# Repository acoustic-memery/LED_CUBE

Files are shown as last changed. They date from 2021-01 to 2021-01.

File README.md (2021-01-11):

# 8X8X8 LED_CUBE


 Code and other bits for my 8x8x8 LED cube

#  File Directory
- CAD_FILES: Includes all CAD used to design 3D printed casing for the cube
- Gerbers_Main: Gerber files generated from my designs in KiCAD and used to manufacture Arduino Breakout PCB
- Gerbers_Secondary: Gerber files generated from my designs in KiCAD and used to manufacture register array PCB
- LED_CUBE_CURRENT: Current software used to run LED cube, all code written in C/C++ on the platformio Arduino framework
- 8x8x8_cube_old.ino: Old Arduino IDE based project
- LED_CUBE_DEMO: HIRE ME :) Demo

#  Project Details

After seeing seeing similar cubes on reddit, I became inspired and wanted to build my own. There were several guides on the internet but they seemed to be using older hardware and could be improved upon significantly. I sought out to do this and designed control PCBs, software, physical casing as well as hand soldered array.

#  How it works:

This cube uses the concept of LED multiplexing, basically only having one of the 8 vertical layers on at once but running through each of these layers so fast that the human eye is tricked and thinks its seeing a still image. More techinically it is controlled by an Arduino Nano to control a single layer of 64 lights. Because the Nano doesn't have 64 GPIO pins, it utilizes 8 of them to write to an 8-bit shift register each. The shift register then "stores" and outputs the associated off or on value for an entire row of 8 lights. Now we have what is essentially a serial to parallel buffer which enables to nano to output a layer at a time. On the Arduino breakout board there is also an external power supply that is designed to work with 7-12 volts input and up to 1.5A input.

See schematics below:

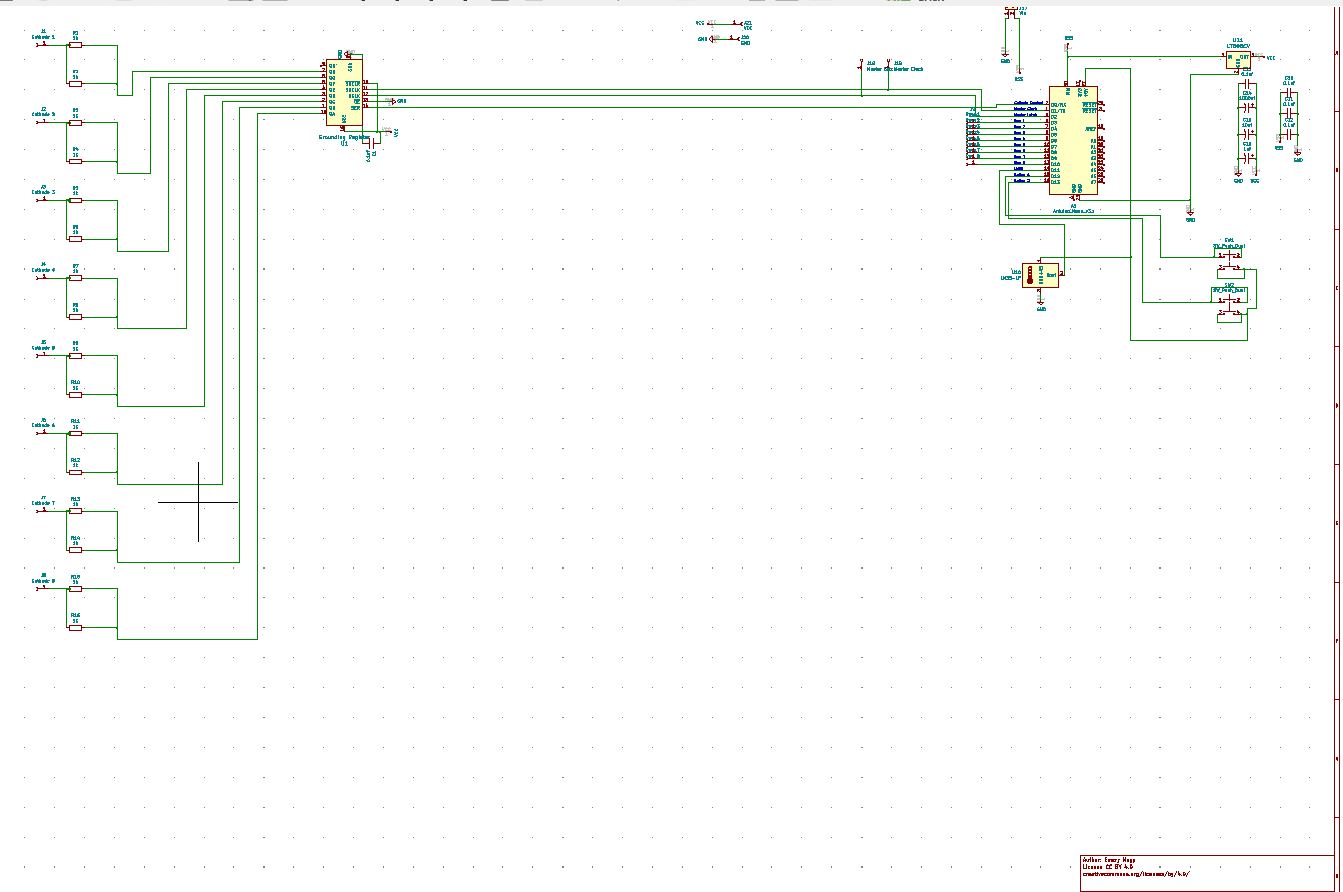
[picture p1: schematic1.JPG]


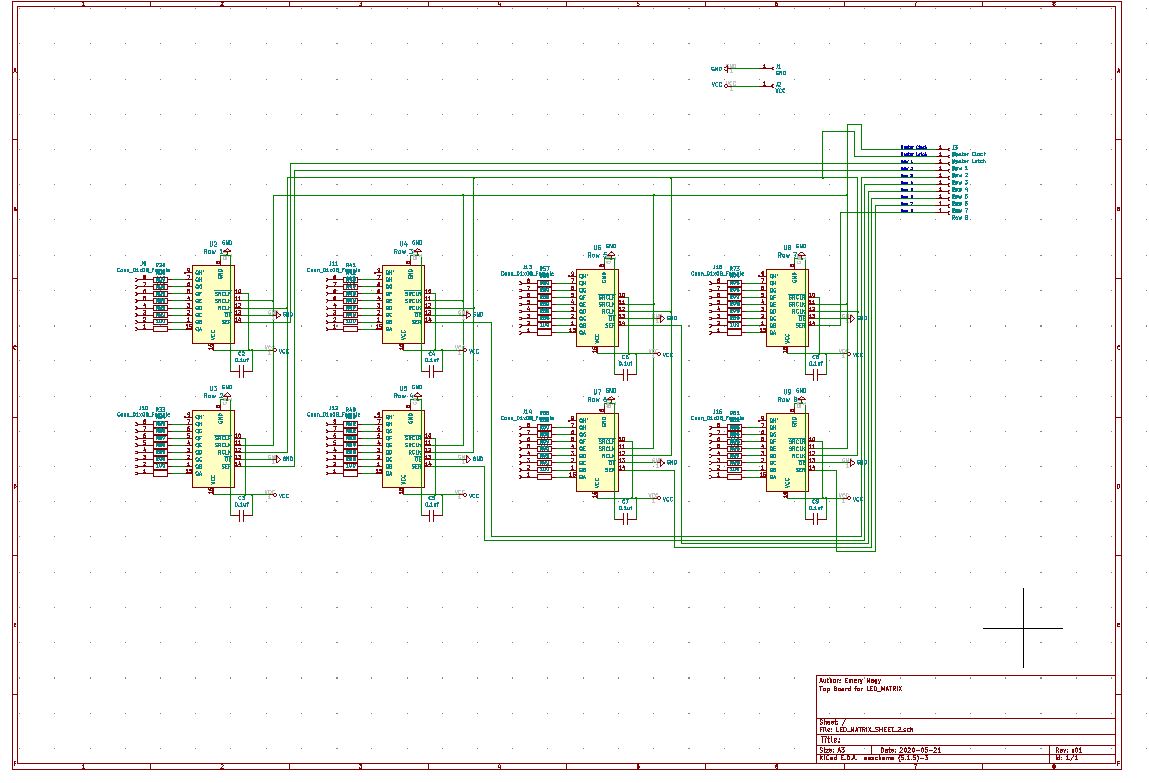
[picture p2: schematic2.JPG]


The software was origionally written just using the basic Arduino IDE, but soon moved over to Platformio for more flexability. The core of the software design involves writing bits to a 2D byte array where each byte can be thought of to corispond to a row in the *X AXIS* of the cube and the other two dimensions of the array can be thought of to contain the *Y AND Z AXIS* accoridingly. In order to output to the shift registers efficiently custom drivers were needed which utiized the idea of "bit banging" or using the digital output of the GPIO to generate the digital signal as well as clock signal.

The housing was designed in SOLIDWORKS and 3D printed in silver/grey PLA. It was designed to be assembled with Zipties because I am classy...

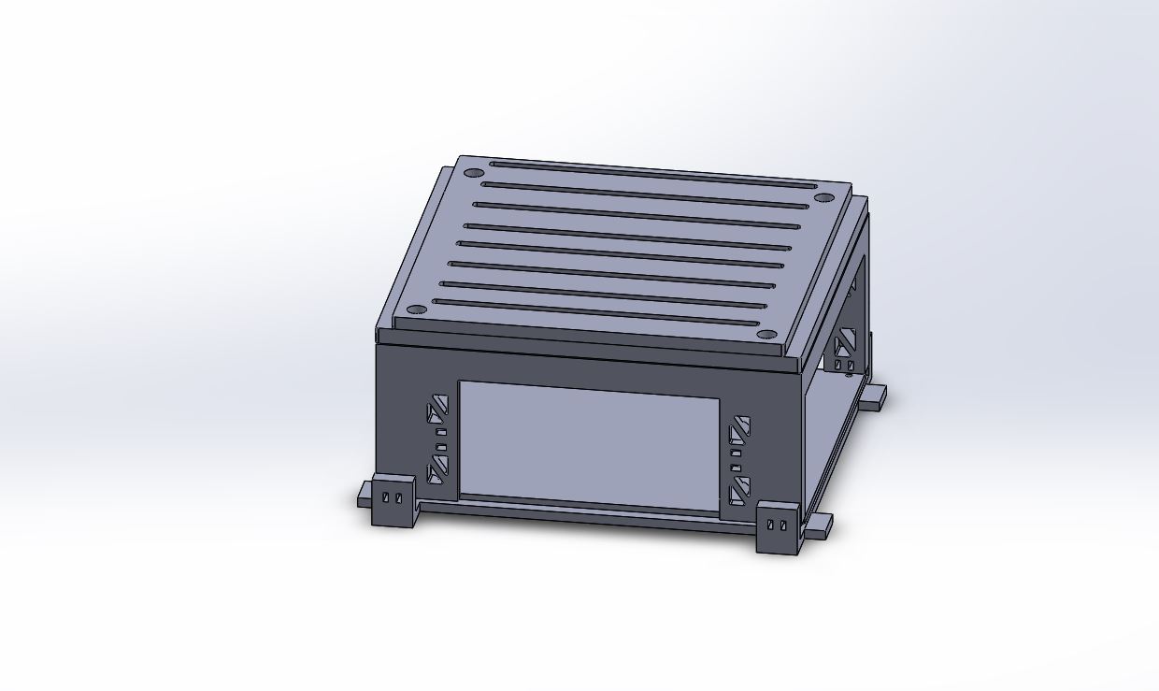
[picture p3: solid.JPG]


Overall this was a super fun project and taught me a lot of awesome skills!

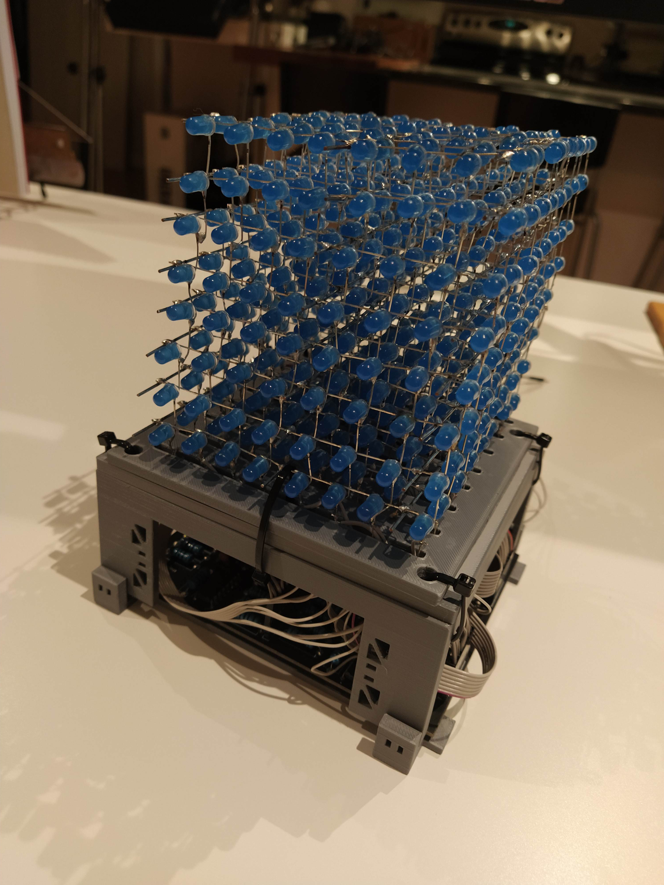
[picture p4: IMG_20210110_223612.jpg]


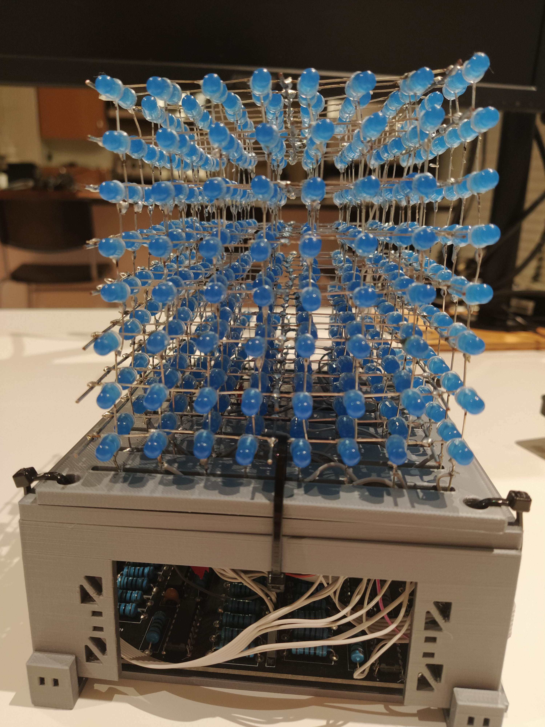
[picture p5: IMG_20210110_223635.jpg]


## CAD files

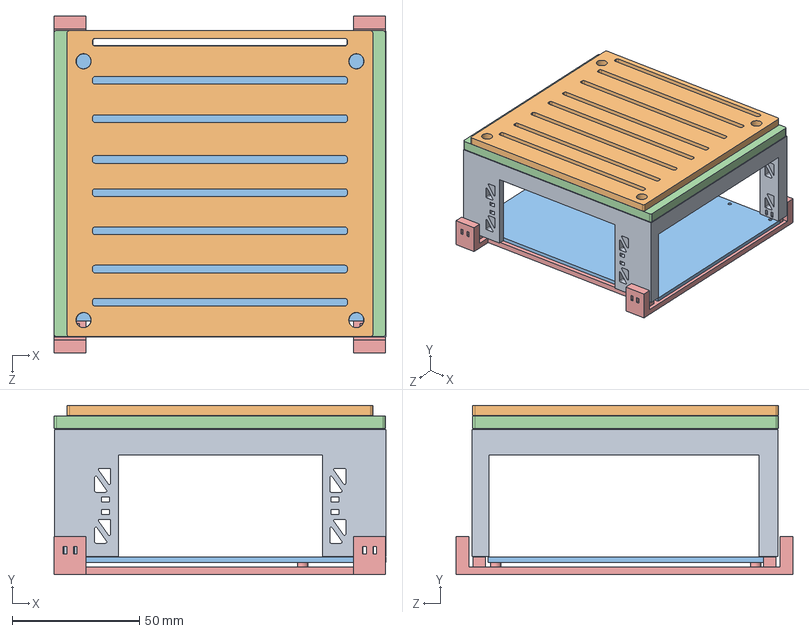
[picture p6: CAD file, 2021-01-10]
CAD_FILES/Assembly master.SLDASM
130.2 x 66.4 x 132.0 mm
Mid Plate 1
Top plate 1
register_PCB
Spacer_Top
register_PCB_Holder

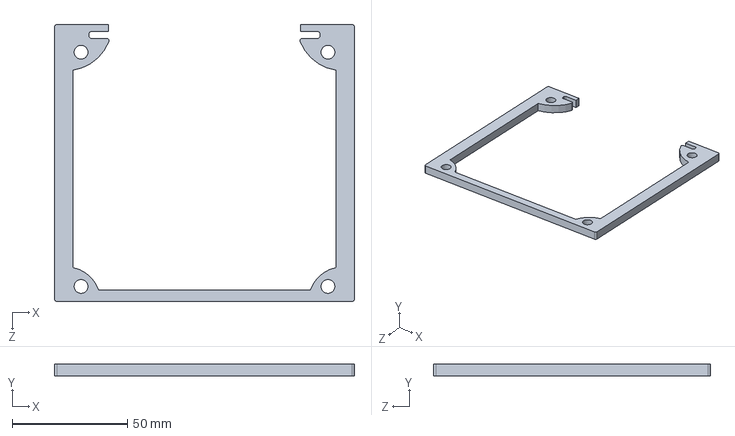
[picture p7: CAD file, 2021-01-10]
CAD_FILES/Spacer_Top.SLDPRT
130.0 x 5.00 x 120.0 mm

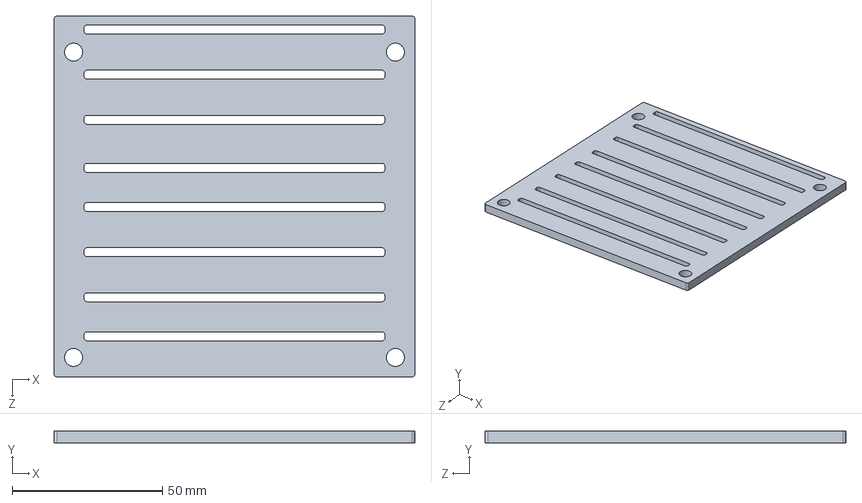
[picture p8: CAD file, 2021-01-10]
CAD_FILES/Top plate 1.SLDPRT
120.0 x 4.00 x 120.0 mm

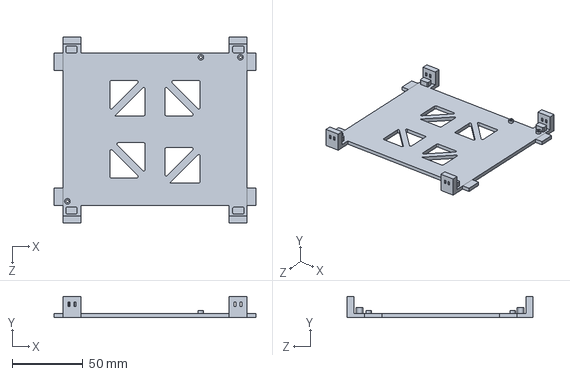
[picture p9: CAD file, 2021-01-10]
CAD_FILES/register_PCB_Holder.SLDPRT
143.0 x 15.0 x 132.0 mm

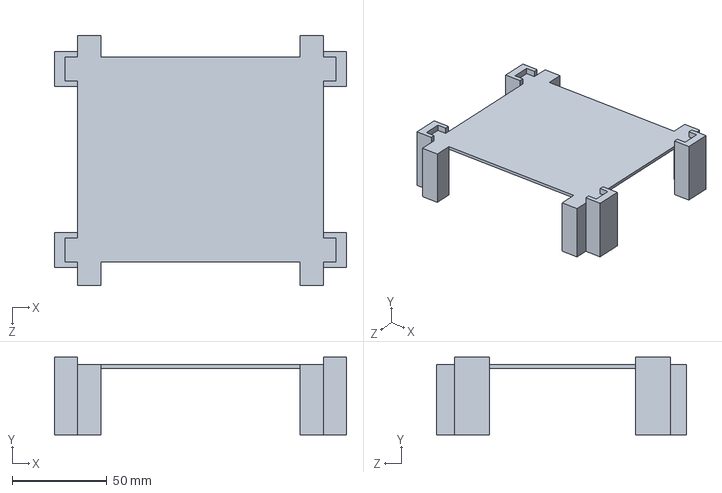
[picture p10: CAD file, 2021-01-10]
CAD_FILES/Controller_PCB_Holder.SLDPRT
154.0 x 41.0 x 132.0 mm

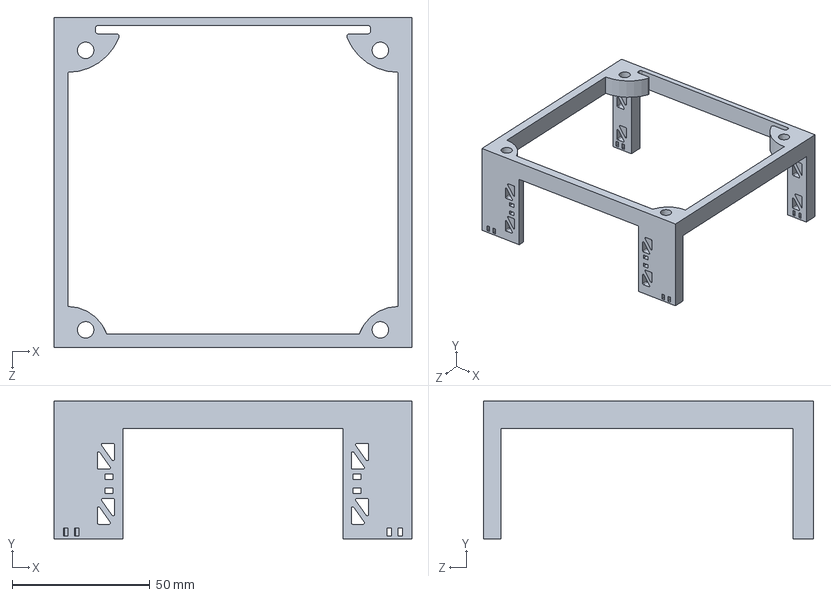
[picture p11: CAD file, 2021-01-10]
CAD_FILES/Mid Plate 1.SLDPRT
130.0 x 50.0 x 120.0 mm

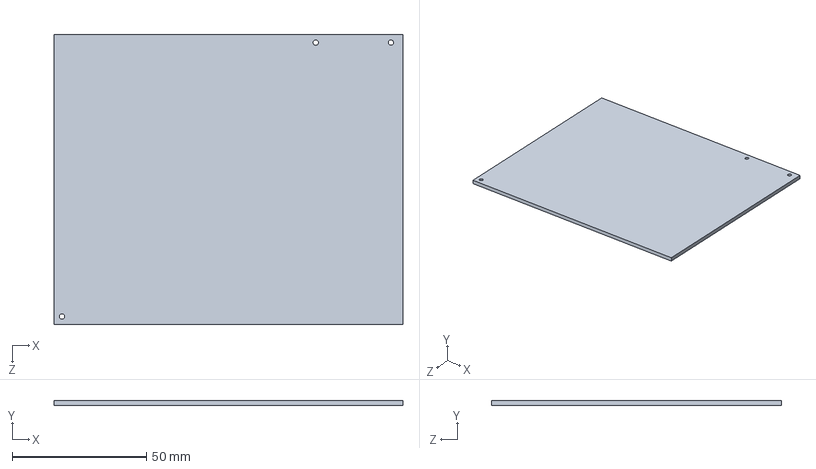
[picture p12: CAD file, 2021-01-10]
CAD_FILES/register_PCB.SLDPRT
130.0 x 2.00 x 108.0 mm

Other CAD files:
CAD_FILES/Mid Plate 1.STL
CAD_FILES/Spacer_Top.STL
CAD_FILES/Top plate 1.3mf
CAD_FILES/Top plate 1.STL
CAD_FILES/register_PCB_Holder.STL

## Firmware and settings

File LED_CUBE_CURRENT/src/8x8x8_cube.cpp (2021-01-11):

//Control Program for an 8x8x8 LED cube
//Author: Emery Nagy
//Date: Aug 21, 2020
//

// Globals
#include <Arduino.h>
#include <SoftwareSerial.h>
#define x_z 0
#define y_z 1
#define x_y 2

const int groundPin = 0;  //data pin for ground layers
const int latchPin = 2; 
const int clockPin = 1;
const int row1 = 3;
const int row2 = 4;
const int row3 = 5;
const int row4 = 6;
const int row5 = 7;
const int row6 = 8;
const int row7 = 9;
const int row8 = 10;
//SoftwareSerial mySerial(11, 12); //soft serial init
 
void setup() {
  // initialize I/O pins
  pinMode(groundPin, OUTPUT);
  pinMode(latchPin, OUTPUT);
  pinMode(clockPin, OUTPUT);
  pinMode(row1, OUTPUT);
  pinMode(row2, OUTPUT);
  pinMode(row3, OUTPUT);
  pinMode(row4, OUTPUT);
  pinMode(row5, OUTPUT);
  pinMode(row6, OUTPUT);
  pinMode(row7, OUTPUT);
  pinMode(row8, OUTPUT);
 
 // mySerial.begin(9600);
}

byte cube[8][8]; //create an empty 2d byte array which can be used to specify y and z axis in which bits get modified


/*////////////////////////////////////////////////////////////////////////////////////////////////////
Custom shiftout function

-> (Output): Draws a complete X-Y layer i.e. 64 flat nodes

-> (PARAM): Takes an 8 bit value for each row where each bit corisponds to a "node on the x axis" and each row corisponds to the equivelent y axis

-> (PARAM): Takes the ground value
    -> "Ground value" needs to be low for the given layer to be on

*///////////////////////////////////////////////////////////////////////////////////////////////////

void shift(uint8_t val,uint8_t val_2, uint8_t val_3, uint8_t val_4, uint8_t val_5, uint8_t val_6, uint8_t val_7, uint8_t val_8, uint8_t val_ground, int frame_delay) //shift out all 8 rows as well as ground layer row
{
    digitalWrite(latchPin,LOW); //lower latch of each register
     uint8_t i;
     for (i = 0; i < 8; i++)  {
                 digitalWrite(row1, !!(val & (1 << i))); //write the bit of each row
                 digitalWrite(row2, !!(val_2 & (1 << i)));
                 digitalWrite(row3, !!(val_3 & (1 << i)));
                 digitalWrite(row4, !!(val_4 & (1 << i)));
                 digitalWrite(row5, !!(val_5 & (1 << i)));
                 digitalWrite(row6, !!(val_6 & (1 << i)));
                 digitalWrite(row7, !!(val_7 & (1 << i)));
                 digitalWrite(row8, !!(val_8 & (1 << i)));
                 digitalWrite(groundPin, !!(val_ground & (1 << i))); //set the ground pin
           digitalWrite(clockPin, HIGH); //write to the clock
           digitalWrite(clockPin, LOW);       
}
   digitalWrite(latchPin,HIGH); //set the latch high
   //delayMicroseconds(frame_delay);
}


/*//////////////////////////////////////////////////////////////////////////////////////////////////
Frame drawing function

-> (Output): Print a whole 3d frame by using the technique of LED multiplexing
  -> LED multiplexing involves setting each layer and running through them very quickly, giving an illusion of a 3D effect


-> (PARAM): iterations: Number of times the frame should be drawn

-> (PARAM): layer: frame layer preset to run (by default to be ground for one layer at a time)

*////////////////////////////////////////////////////////////////////////////////////////////////////
void frame(int f_delay[], int iterations, uint8_t layer[]){ //shift out all 64 bytes in frame buffer
  int n;
  for(n = 0; n < iterations; n++){ //run the total number of iterations
  int i;
  for (i = 0; i < 8; i++){ //run through each layer in the frame buffer
   shift(cube[0][i], cube[1][i], cube[2][i], cube[3][i], cube[4][i], cube[5][i], cube[6][i], cube[7][i], layer[i], f_delay[i]); //shiftout layers
  }}  
  }

uint8_t layer[8] = {B01111111, B10111111, B11011111, B11101111, B11110111, B11111011, B11111101, B11111110}; //ground layer presets

int delay_amount[8] = {5, 5, 5, 5, 5, 5, 5, 5}; //delay presets

int inRange(int num){ //chack if inputs fit within the 8x8x8 cube
  if (0 <=num <=7){
    return 1;
    }
    else{
      return 0;
      }}

/*//////////////////////////////////////////////////////////////////////////////////////////////////////////////////////////

setNode and clearNode

-> (PARAM): x, y, z: The address (physical location) of bit to be set or cleared

-> (OUTPUT): set or clear specific node at value x, y, z
*//////////////////////////////////////////////////////////////////////////////////////////////////////////////////////////
void setNode(int x, int y, int z){ //set a specified node at x, y, z
  if ((inRange(x)) && (inRange(y)) && (inRange(z))){ //make sure that the node to be set is in range of the cube and buffer
  cube[y][z] |= (1<< x);}} //run bitwise operation to set the specified bit 

void clearNode(int x, int y, int z){ //clear a specified node at x,y,z
  if ((inRange(x)) && (inRange(y)) && (inRange(z))){ //make sure that the node to be set is in range of the cube and buffer
  cube[y][z] &= ~(1<<x);}} //run bitwise operation to set the specified bit


/*//////////////////////////////////////////////////////////////////////////////////////////////////////////////////////////

set_col

-> (OUTPUT): Sets whole column based on specified x,y location

-> (PARAMS): Takes int x and int y values

*//////////////////////////////////////////////////////////////////////////////////////////////////////////////////////////
void set_col(int x, int y){ //set whole column
  int i;
  for(i=0; i < 8; i++){ 
    setNode(x, y, i); //set a node at specified x,y value through all 8 layers
    }}

/*//////////////////////////////////////////////////////////////////////////////////////////////////////////////////////////

clear_col

-> (OUTPUT): Clear whole column based on specified x,y location

-> (PARAMS): Takes int x and int y values

*//////////////////////////////////////////////////////////////////////////////////////////////////////////////////////////
void clear_col(int x, int y){ //clear whole column
  int i;
  for(i=0; i < 8; i++){
    clearNode(x, y, i); //clear a node at specified x,y value through all 8 layers
    }}


/*//////////////////////////////////////////////////////////////////////////////////////////////////////////////////////////

set_row

-> (OUTPUT): Set whole row down the x axis of nodes

-> (PARAMS): Takes int y and int z values

*//////////////////////////////////////////////////////////////////////////////////////////////////////////////////////////
void set_row(int y, int z){ //set row down x axis
  int i;
  for(i=0; i<8; i++){
    setNode(i, y, z); //set node at specified y,z value through all 8 nodes down the x axis
    }}

/*//////////////////////////////////////////////////////////////////////////////////////////////////////////////////////////

clear_row

-> (OUTPUT): Clear whole row down the x axis of nodes

-> (PARAMS): Takes int y and int z values

*//////////////////////////////////////////////////////////////////////////////////////////////////////////////////////////
void clear_row(int y, int z){  //clear row down x axis
  int i;
  for(i=0; i<8; i++){
    clearNode(i, y, z);//clear node at specified y,z value through all 8 nodes down the x axis
    }}


/*//////////////////////////////////////////////////////////////////////////////////////////////////////////////////////////

set_ray

-> (OUTPUT): Set whole row down the y axis of nodes

-> (PARAMS): Takes int x and int z values

*//////////////////////////////////////////////////////////////////////////////////////////////////////////////////////////
void set_ray(int x, int z){  //set row down y axis
  int i;
  for(i=0; i<8; i++){
    setNode(x, i, z); //set node at specified x,z value through all 8 nodes down the y axis
    }}



/*//////////////////////////////////////////////////////////////////////////////////////////////////////////////////////////

clear_ray

-> (OUTPUT): Clear whole row down the y axis of nodes

-> (PARAMS): Takes int x and int z values

*//////////////////////////////////////////////////////////////////////////////////////////////////////////////////////////

void clear_ray(int x, int z){ //clear row down y axis
  int i;
  for(i=0; i<8; i++){
    clearNode(x, i, z);//clear node at specified x,z value through all 8 nodes down the y axis
    }}

    

/*//////////////////////////////////////////////////////////////////////////////////////////////////////////////////////////

set_plane

-> (OUTPUT): Set whole 2D plane with specified orientation

-> (PARAMS): Takes orientation and the starting position of the 2D plane

*//////////////////////////////////////////////////////////////////////////////////////////////////////////////////////////
void set_plane(int orientation, int start_point){
  if (orientation == x_y){ //if the orientation is set vertically
    int i;
    for(i = 0; i < 8; i++){
      set_col(i, start_point); //set columns down the x axis at specified y value
      }
    }
     if (orientation == y_z){ //if the orientation is set horizontally
    int n;
    for(n = 0; n < 8; n++){
      set_ray(n, start_point); //set rays down the x axis at specified z value
      }
    }
  }


/*//////////////////////////////////////////////////////////////////////////////////////////////////////////////////////////

clear_plane

-> (OUTPUT): Clear whole 2D plane with specified orientation

-> (PARAMS): Takes orientation and the starting position of the 2D plane

*//////////////////////////////////////////////////////////////////////////////////////////////////////////////////////////
void clear_plane(int orientation, int start_point){
  if (orientation == x_y){ //if the orientation is set vertically
    int i;
    for(i = 0; i < 8; i++){
      clear_col(i, start_point);     //clear columns down the x axis at specified y value
      }
    } 

    if (orientation == y_z){  //if the orientation is set horizontally
    int n;
    for(n = 0; n < 8; n++){
      clear_ray(n, start_point);    //clear rays down the x axis at specified z value
      }
    } 
  }


/*//////////////////////////////////////////////////////////////////////////////////////////////////////////////////////////

clear_cube

-> (OUTPUT): Clears whole cube in all 3 axis (Turns off all LED's)

-> (PARAMS): NONE

*//////////////////////////////////////////////////////////////////////////////////////////////////////////////////////////
void clear_cube(){
  int i;
  for (i=0; i<8; i++){
    clear_plane(x_y, i);
  }
}  



/*//////////////////////////////////////////////////////////////////////////////////////////////////////////////////////////

set_random

-> (OUTPUT): sets a specified number of random nodes on in a specified range, if node is already on it remains on

-> (PARAMS): int numRand: number of random nodes to be set on 
            int range: value in between 0 and 8 inclusive to be the absolute range the random values are allowed to be in

*//////////////////////////////////////////////////////////////////////////////////////////////////////////////////////////
void set_random(int numRand, int range){
int i;
for(i=0;i<numRand;i++){ 
  int randX = random(0, range); //random x value
  int randY = random(0, range); //random y value
  int randZ = random(0, range); //random z value
  setNode(randX, randY, randZ); //set a node on with the random x,y,z values
}
}

/*//////////////////////////////////////////////////////////////////////////////////////////////////////////////////////////

clear_random

-> (OUTPUT): clear a specified number of random nodes on in a specified range, if node is already off it remains off

-> (PARAMS): int numRand: number of random nodes to be set off
            int range: value in between 0 and 8 inclusive to be the absolute range the random values are allowed to be in

*//////////////////////////////////////////////////////////////////////////////////////////////////////////////////////////
void clear_random(int numRand, int range){
int i;
for(i=0;i<numRand;i++){
  int randX = random(0, range);//random x value
  int randY = random(0, range);//random y value
  int randZ = random(0, range);//random z value
  clearNode(randX, randY, randZ);//set a node off with the random x,y,z values
}
}


/*//////////////////////////////////////////////////////////////////////////////////////////////////////////////////////////

full_test_demo

-> (OUTPUT): A preprogramed sequence which sets each plane on and off one by one in both the veritcal (x_y) and horizontal (x_z) directions

-> (PARAMS): NONE

*//////////////////////////////////////////////////////////////////////////////////////////////////////////////////////////
void full_test_demo(){
set_plane(x_y, 0);
frame(delay_amount, 100,layer);
clear_plane(x_y, 0);
frame(delay_amount, 100,layer);


set_plane(x_y, 1);
frame(delay_amount, 100,layer);
clear_plane(x_y, 1);
frame(delay_amount, 100,layer);

set_plane(x_y, 2);
frame(delay_amount, 100,layer);
clear_plane(x_y, 2);
frame(delay_amount, 100,layer);

set_plane(x_y, 3);
frame(delay_amount, 100,layer);
clear_plane(x_y, 3);
frame(delay_amount, 100,layer);

set_plane(x_y, 4);
frame(delay_amount, 100,layer);
clear_plane(x_y, 4);
frame(delay_amount, 100,layer);

set_plane(x_y, 5);
frame(delay_amount, 100,layer);
clear_plane(x_y, 5);
frame(delay_amount, 100,layer);  

set_plane(x_y, 6);
frame(delay_amount, 100,layer);
clear_plane(x_y, 6);
frame(delay_amount, 100,layer);

set_plane(x_y, 7);
frame(delay_amount, 100,layer);
clear_plane(x_y, 7);
frame(delay_amount, 100,layer);


set_plane(y_z, 0);
frame(delay_amount, 100,layer);
clear_plane(y_z, 0);
frame(delay_amount, 100,layer);


set_plane(y_z, 1);
frame(delay_amount, 100,layer);
clear_plane(y_z, 1);
frame(delay_amount, 100,layer);

set_plane(y_z, 2);
frame(delay_amount, 100,layer);
clear_plane(y_z, 2);
frame(delay_amount, 100,layer);

set_plane(y_z, 3);
frame(delay_amount, 100,layer);
clear_plane(y_z, 3);
frame(delay_amount, 100,layer);

set_plane(y_z, 4);
frame(delay_amount, 100,layer);
clear_plane(y_z, 4);
frame(delay_amount, 100,layer);

set_plane(y_z, 5);
frame(delay_amount, 100,layer);
clear_plane(y_z, 5);
frame(delay_amount, 100,layer);  

set_plane(y_z, 6);
frame(delay_amount, 100,layer);
clear_plane(y_z, 6);
frame(delay_amount, 100,layer);

set_plane(y_z, 7);
frame(delay_amount, 100,layer);
clear_plane(y_z, 7);
frame(delay_amount, 100,layer);
}


/*//////////////////////////////////////////////////////////////////////////////////////////////////////////////////////////
H
-> (OUTPUT): Draws a letter H in the x_z direction at specified y value

-> (PARAMS): int i: y value for the letter to be drawn on
*//////////////////////////////////////////////////////////////////////////////////////////////////////////////////////////
void H (int i){
set_col(1,i);
set_col(0,i);
set_col(6,i);
set_col(7,i);
set_row(i,4);
set_row(i,3);
frame(delay_amount, 50,layer);
clear_cube();
}

/*//////////////////////////////////////////////////////////////////////////////////////////////////////////////////////////
I
-> (OUTPUT): Draws a letter I in the x_z direction at specified y value

-> (PARAMS): int i: y value for the letter to be drawn on
*//////////////////////////////////////////////////////////////////////////////////////////////////////////////////////////
void I (int i){
set_col(4,i);
set_col(3,i);
frame(delay_amount, 50,layer);
clear_cube();
}

/*//////////////////////////////////////////////////////////////////////////////////////////////////////////////////////////
R
-> (OUTPUT): Draws a letter R in the x_z direction at specified y value

-> (PARAMS): int i: y value for the letter to be drawn on
*//////////////////////////////////////////////////////////////////////////////////////////////////////////////////////////
void R (int i){
  
set_col(0,i);
set_col(1,i);
set_col(4,i);
set_col(5,i);
set_row(i,7);
set_row(i,6);
set_row(i,3);
set_row(i,2);
clearNode(7,i,7);
clearNode(6,i,7);
clearNode(7,i,6);
clearNode(6,i,6);
clearNode(5,i,7);
clearNode(4,i,7);
clearNode(5,i,6);
clearNode(4,i,6);
clearNode(7,i,3);
clearNode(6,i,3);
clearNode(7,i,2);
clearNode(6,i,2);
clearNode(5,i,3);
clearNode(4,i,2);
clearNode(5,i,3);
clearNode(4,i,2);
frame(delay_amount, 50,layer);
clear_cube();
}

/*//////////////////////////////////////////////////////////////////////////////////////////////////////////////////////////
E
-> (OUTPUT): Draws a letter E in the x_z direction at specified y value

-> (PARAMS): int i: y value for the letter to be drawn on
*//////////////////////////////////////////////////////////////////////////////////////////////////////////////////////////
void E (int i){
set_col(0,i);
set_col(1,i);
set_row(i,7);
set_row(i,6);
set_row(i,0);
set_row(i,1);
set_row(i,4);
set_row(i,3);
clearNode(7,i,7);
clearNode(6,i,7);
clearNode(7,i,6);
clearNode(6,i,6);
clearNode(7,i,1);
clearNode(6,i,1);
clearNode(7,i,0);
clearNode(6,i,0);
clearNode(7,i,4);
clearNode(6,i,4);
clearNode(7,i,3);
clearNode(6,i,3);
frame(delay_amount, 50,layer);
clear_cube();

}

/*//////////////////////////////////////////////////////////////////////////////////////////////////////////////////////////
M
-> (OUTPUT): Draws a letter M in the x_z direction at specified y value

-> (PARAMS): int i: y value for the letter to be drawn on
*//////////////////////////////////////////////////////////////////////////////////////////////////////////////////////////
void M (int i){

set_col(7,i);
set_col(6,i);
set_col(0,i);
set_col(1,i);
setNode(2,i,5);
setNode(5,i,5);
setNode(2,i,4);
setNode(3,i,4);
setNode(4,i,4);
setNode(5,i,4);
setNode(3,i,3);
setNode(4,i,3);
frame(delay_amount, 50,layer);
clear_cube();
}

/*//////////////////////////////////////////////////////////////////////////////////////////////////////////////////////////
happy_face
-> (OUTPUT): Draws a happy face in the x_z direction at specified y value

-> (PARAMS): int i: y value for the letter to be drawn on
*//////////////////////////////////////////////////////////////////////////////////////////////////////////////////////////

void happy_face(int i){


setNode(3,i,4);
setNode(4,i,4);
setNode(3,i,3);
setNode(4,i,3);

setNode(1,i,5);
setNode(2,i,5);
setNode(1,i,6);
setNode(2,i,6);


setNode(5,i,5);
setNode(6,i,5);
setNode(5,i,6);
setNode(6,i,6);

setNode(4,i,0);
setNode(5,i,0);
setNode(4,i,1);
setNode(5,i,1);
setNode(3,i,0);
setNode(2,i,0);
setNode(3,i,1);
setNode(2,i,1);

setNode(0,i,1);
setNode(1,i,1);
setNode(0,i,2);
setNode(1,i,2);

setNode(7,i,1);
setNode(6,i,1);
setNode(7,i,2);
setNode(6,i,2);

frame(delay_amount, 50,layer);
clear_cube();


}

/*//////////////////////////////////////////////////////////////////////////////////////////////////////////////////////////
hire_me
-> (OUTPUT): Draws a sequence that reads HIRE ME :) 

-> (PARAMS): NONE
*//////////////////////////////////////////////////////////////////////////////////////////////////////////////////////////
void hire_me(){

int i;
for(i=8; i>=0; i--){
  H(i);}
for(i=8; i>=0; i--){
  I(i);}
for(i=8; i>=0; i--){
  R(i);}
for(i=8; i>=0; i--){
  E(i);}  
for(i=8; i>=0; i--){
  M(i);}
for(i=8; i>=0; i--){
  E(i);}
for(i=8; i>=0; i--){
  happy_face(i);}
}

/*//////////////////////////////////////////////////////////////////////////////////////////////////////////////////////////
rand_demo
-> (OUTPUT): Draws a random sequence of LED lights on and off 

-> (PARAMS): NONE
*//////////////////////////////////////////////////////////////////////////////////////////////////////////////////////////
void rand_demo(){
set_random(3,8);
frame(delay_amount, 30,layer);
clear_random(3,8);
}

void loop() {
 
hire_me();




}

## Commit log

2020-12-28 Add Gerber files for both control boards
    [LED_MATRIX-B_Cu.gbr, LED_MATRIX-B_Mask.gbr, LED_MATRIX-B_SilkS.gbr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]
2021-01-10 Add Updated Platformio Project as well as casing CAD files
    [Assembly master.SLDASM, Controller_PCB_Holder.SLDPRT, Mid Plate 1.SLDPRT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]
2021-01-10 Changed some formatting
    [Assembly master.SLDASM, Controller_PCB_Holder.SLDPRT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]
